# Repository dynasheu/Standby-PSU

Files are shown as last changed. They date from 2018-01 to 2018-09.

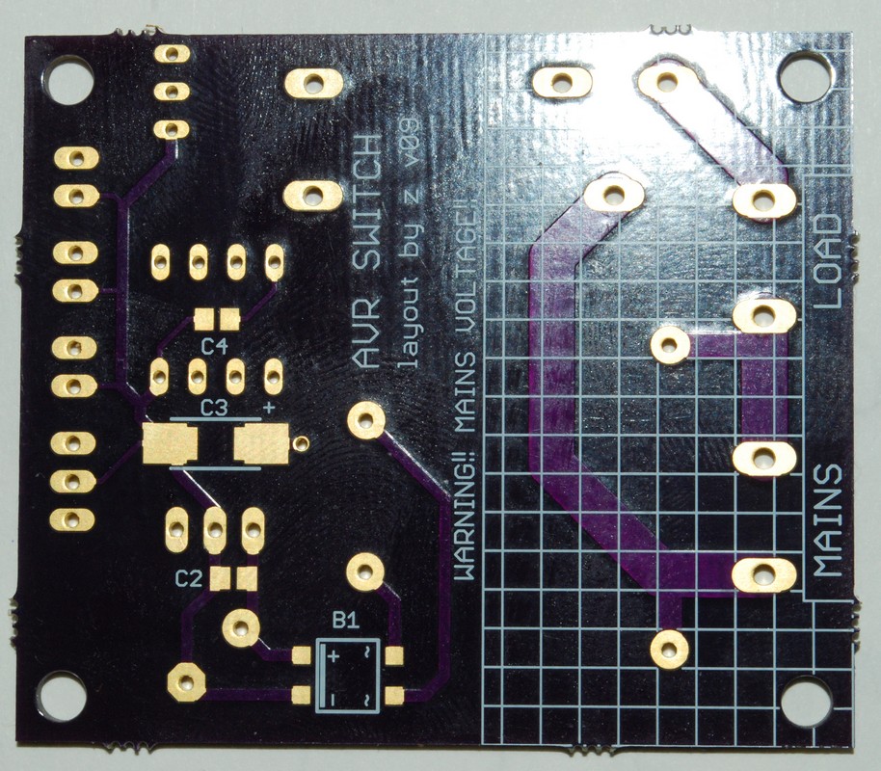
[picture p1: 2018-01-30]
prototype/avr3_v09_cr.jpg

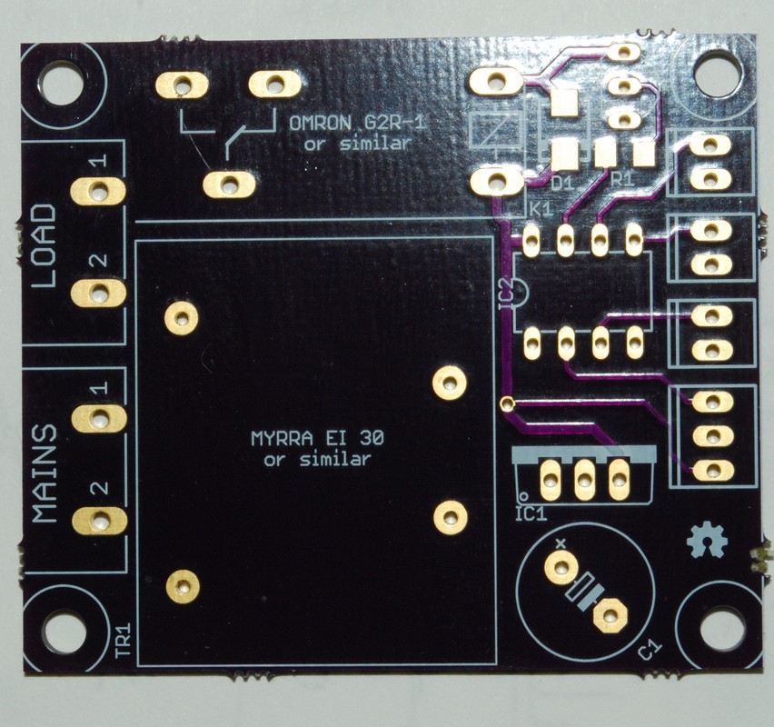
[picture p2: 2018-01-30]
prototype/avr2_v09_cr.jpg

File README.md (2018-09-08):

# Standby-PSU
Small sandby PSU for low power applications.

## standby-psu-test
This sketch is for debugging and testing on arduino. Uses normal IRremote.h library.

## standby-psu-master
This sketch is for use with ATTiny.
Uses tiny_IRremote.h and SendOnlySoftwareSerial.h libraries.

I/O:
- button
- led
- relay
- ir
- serial out

PCB and components coming soon

## standby-psu-slave
Comming soon.

This sketch is for use with ATTiny.
Uses ReceiveOnlySoftwareSerial.h library.

I/O:
- button
- led
- relay
- mute relay
- serial in

Same PCB as master.

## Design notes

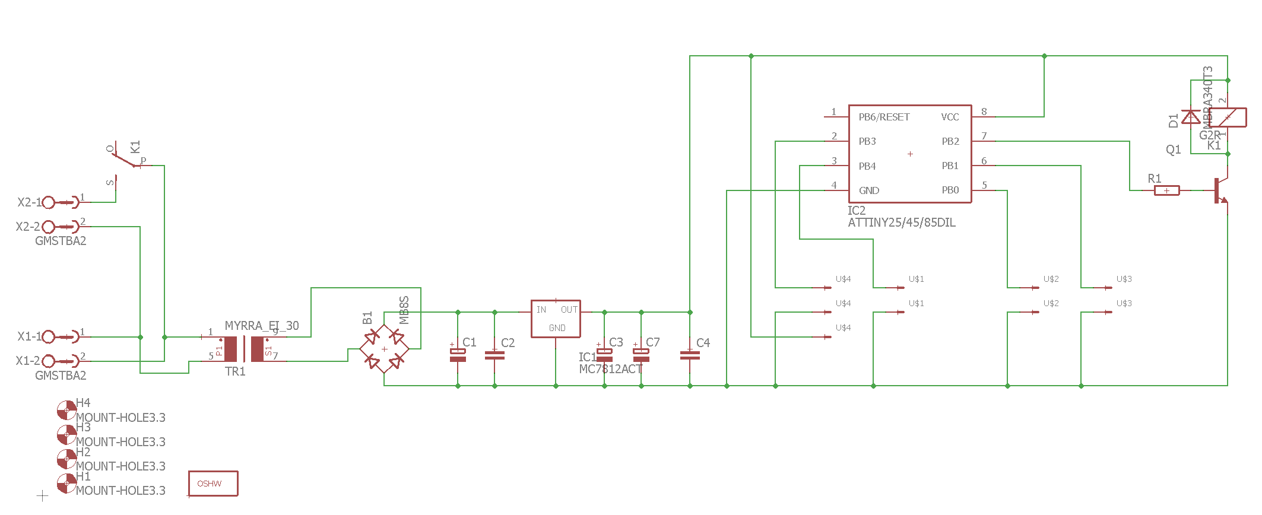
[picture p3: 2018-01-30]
prototype/schematic_avr_v09.PNG

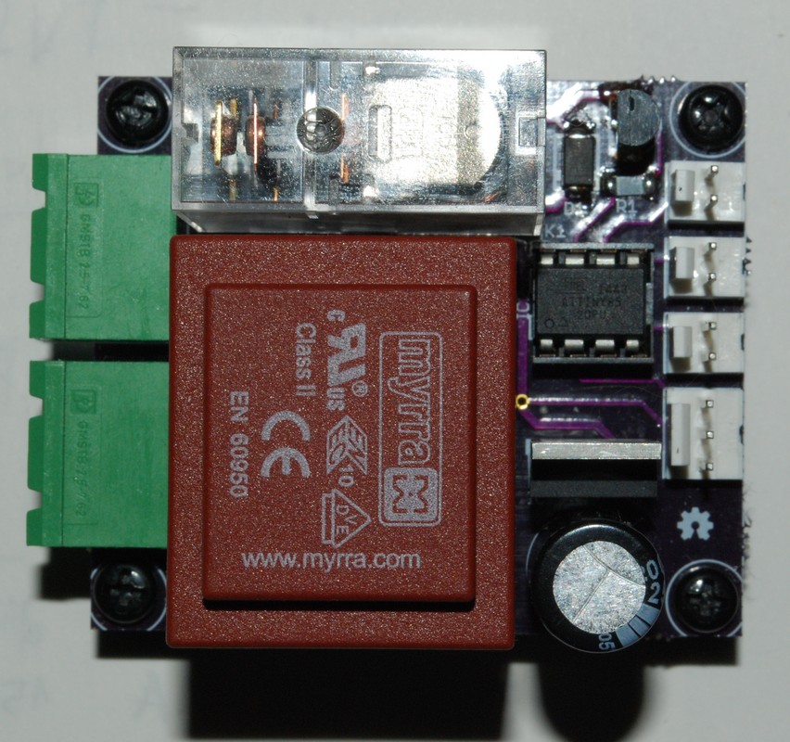
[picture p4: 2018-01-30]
prototype/avr1_v09_cr.jpg

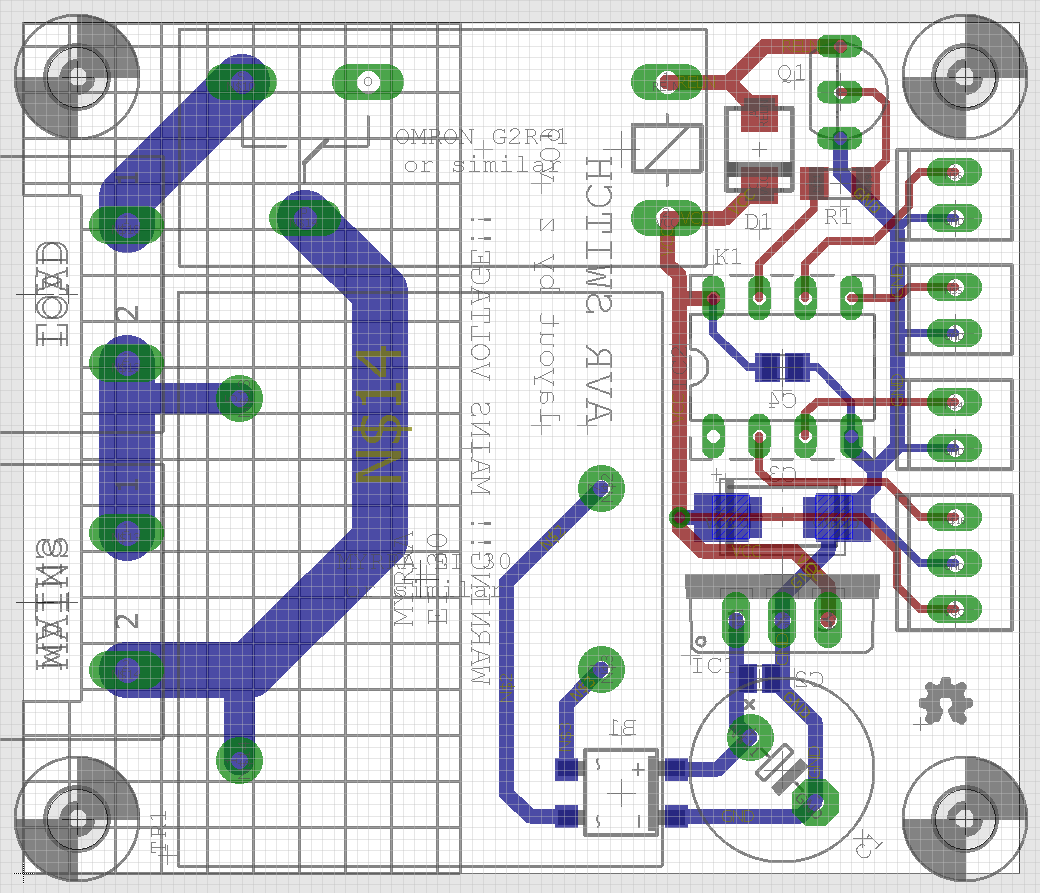
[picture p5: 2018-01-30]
prototype/pcb_avr_v09.PNG

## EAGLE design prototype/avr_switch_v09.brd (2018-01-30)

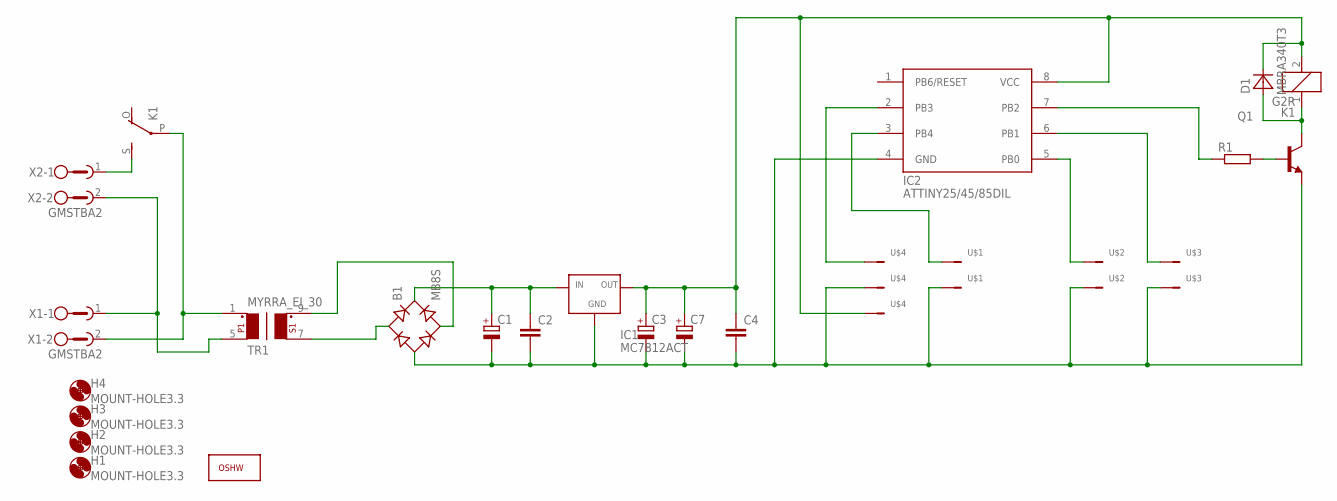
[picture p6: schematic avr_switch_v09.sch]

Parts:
B1: MB8S; SOIC-4
C1: CPOL-EUE5-10.5; E5-10,5
C2, C4: C-EUC0805; C0805
C3: CPOL-EUCT6032; CT6032
C7: CPOL-EUD/7343-31W; D/7343-31W
D1: MBRA340T3; SMA
H1, H2, H3, H4: MOUNT-HOLE3.3; 3,3
IC1: MC7812ACT; TO220V
IC2: ATTINY25/45/85DIL; DIL08
K1: G2R
Q1: BC548-NPN-TO92-CBE; TO92-CBE
R1: R-EU_R1206; R1206
TR1: MYRRA_EI_30; MYRRA-EI30
U$1, U$2, U$3: MOLEX-VERT-KK-2-; MOLEX-KK-VERT-2PIN
U$4: MOLEX-VERT-KK-3-3PIN; MOLEX-KK-VERT-3PIN
U$5: OSHWOSHW_TOP; OSHW_F
X1, X2: GMSTBA2

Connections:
GND: B1.-, C1.-, C2.2, C3.-, C4.2, C7.-, IC1.2 (GND), IC2.4 (GND), Q1.E, U$1.1, U$2.1, U$3.1, U$4.2
unnamed: IC2.7 (PB2), R1.1
unnamed: B1.~1 (AC1), TR1.7
unnamed: B1.~2 (AC2), TR1.9
unnamed: IC2.3 (PB4), U$1.2
unnamed: IC2.5 (PB0), U$2.2
unnamed: IC2.6 (PB1), U$3.2
unnamed: Q1.B, R1.2
unnamed: K1.S, X2.1
unnamed: B1.+, C1.+, C2.1, IC1.1 (IN)
unnamed: TR1.5, X1.1, X2.2
unnamed: K1.P, TR1.1, X1.2
unnamed: IC2.2 (PB3), U$4.3
RELN: D1.A, K1.1, Q1.C
VCC: C3.+, C4.1, C7.+, D1.C, IC1.3 (OUT), IC2.8 (VCC), K1.2, U$4.1

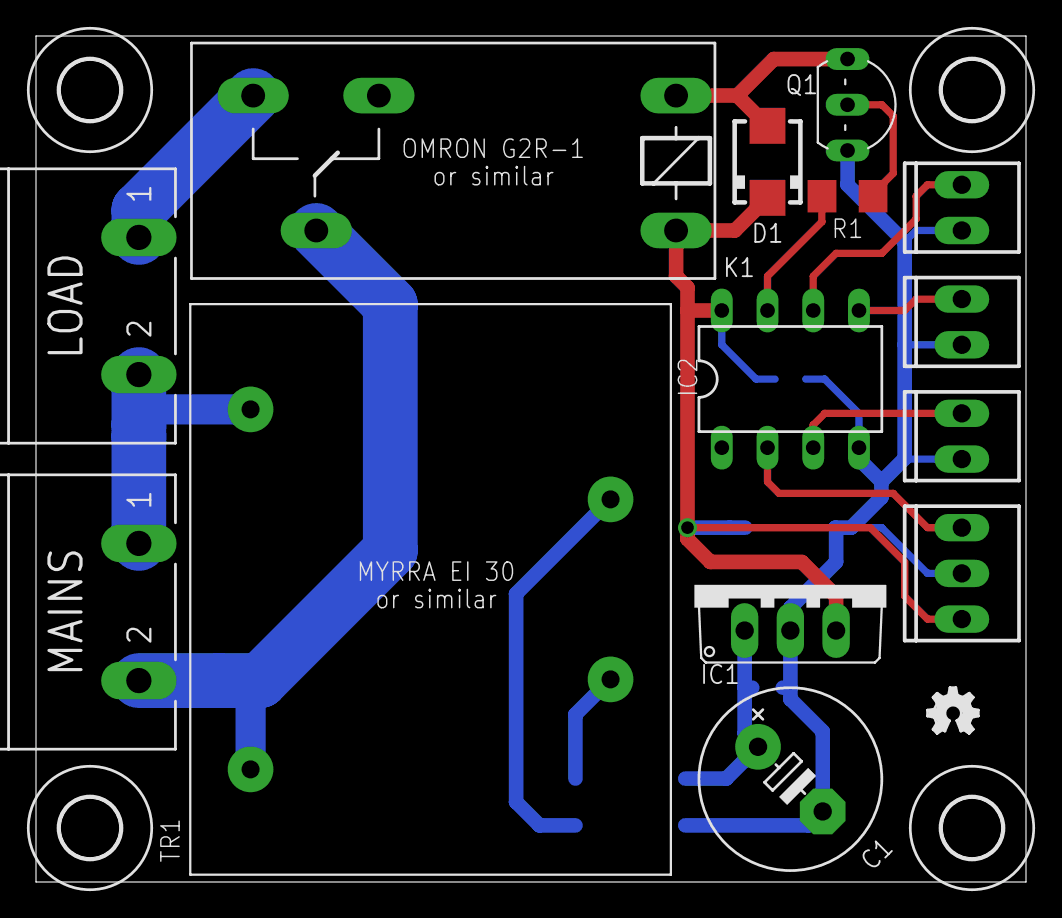
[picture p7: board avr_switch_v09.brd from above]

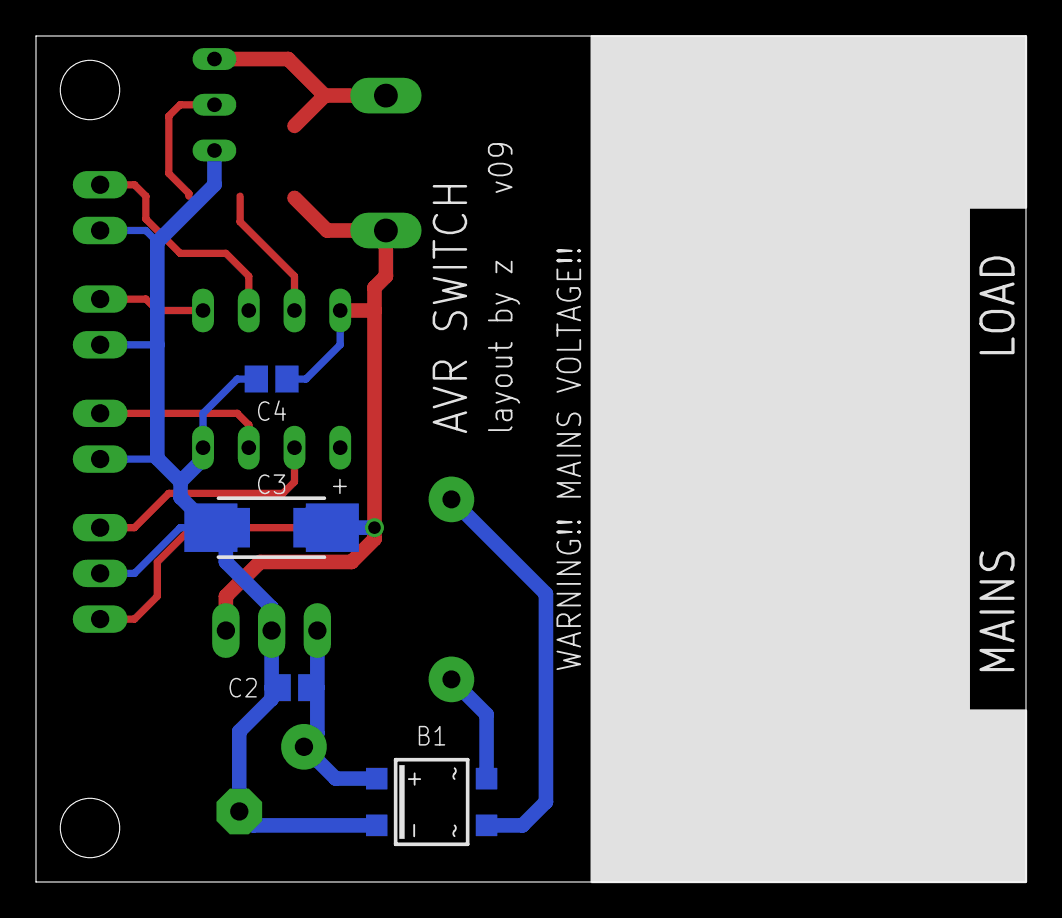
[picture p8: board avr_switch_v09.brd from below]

Board: 2 copper layers, 55.0 x 47.0 mm, 24 parts (5 on the bottom side), 15 nets.

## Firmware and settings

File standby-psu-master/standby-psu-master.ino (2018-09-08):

// load libraries
#include "tiny_IRremote.h"
#include "SendOnlySoftwareSerial.h"

// pinout
#define relayPin PB2                            // ATtiny pin 7
#define ledPin PB1                              // ATtiny pin 6
#define buttonPin PB0                           // ATtiny pin 5
#define serialOutPin PB4                        // ATtiny pin 3
#define irPin PB3                               // ATtiny pin 2

bool ledState = HIGH;                           // state of standby led. turned HIGH when system is off
bool powerState = LOW;                          // power state, LOW when system is off
bool enablePower = HIGH;                        // enable power state change
bool powerSent = LOW;                           // flag to send power down serial out

int debounceDelay = 50;                         // debounce time
unsigned long powerStateTimer = 0;              // time snapshot when power state changed
unsigned long blinkTimer = 0;                   // blink timer
int powerStateDelay = 15000;                    // power state delay time
bool pauseLoop = LOW;                           // pause main loop

// IR setup
IRrecv irrecv(irPin);
decode_results results;

unsigned long muteTimer = 0;                    // millis snapshot when we press mute button on ir (repeating signal)
bool irMute = LOW;                              // check if we can change mute state again with ir
bool irPower = LOW;                             // signal to change power state from ir

// Software serial
SendOnlySoftwareSerial mySerial (serialOutPin);       // Tx pin

void setup() {
    // serial setup
    mySerial.begin (9600);

    // pinout setup
    pinMode(buttonPin, INPUT_PULLUP);
    pinMode(ledPin, OUTPUT);
    pinMode(irPin, INPUT);
    pinMode(relayPin, OUTPUT);
    pinMode(serialOutPin, OUTPUT);

    // defaults
    digitalWrite(ledPin, ledState);
    digitalWrite(relayPin, powerState);

    // ir setup
    irrecv.enableIRIn();
}

void loop() {
    // startup and shutdown blinking led
    if (millis() - powerStateTimer < powerStateDelay) {
        // disable power button
        enablePower = LOW;

        // blink led every second
        if(millis() - blinkTimer > 1000) {
            digitalWrite(ledPin, HIGH);
            delay(debounceDelay);
            digitalWrite(ledPin, LOW);
            blinkTimer = millis();
        }
    }
    else {
        // enable power button
        enablePower = HIGH;

        // reset led state
        digitalWrite(ledPin, ledState);
    }

    // microsoft xbox one media remote - NEC standard
    // 18556633 - logo
    // 18577033 - window
    // 18609673 - lines
    // 18577543 - up
    // 18610183 - down
    // 18547963 - left
    // 18580603 - right
    // 18564283 - center
    // 18596923 - back
    // 18572443 - line dot
    // 18589783 - rewind
    // 18550513 - play
    // 18557143 - forward
    // 18602023 - previous
    // 18585703 - stop
    // 18569383 - next

    // repeating codes
    // 18548983 - volume up
    // 18581623 - volume down
    // 18575503 - mute
    // 18565303 - channel up
    // 18597943 - channel down

    // 4294967295 - resend data

    // read ir
    if (irrecv.decode(&results)) {
        if (results.value == 18556633) { // logo button as power on or off
//            mySerial.println("     ");
            irPower = HIGH;
        }
        if (results.value == 18575503 && irMute == LOW) { // mute button
            mySerial.println("0202");
            irMute = HIGH;
            muteTimer = millis();
        }
        if (results.value == 18548983) { // volume up
            mySerial.println("0301");
        }
        if (results.value == 18581623) { // volume down
            mySerial.println("0302");
        }
        if (results.value == 18609673) { // lines button as change output
            mySerial.println("0401");
        }
        if (results.value == 18577033) { // squares button as change input
            mySerial.println("0501");
        }
        irrecv.resume(); // Receive the next value
    }

    // read button
    int buttonPress = 0;
    while (digitalRead(buttonPin) == LOW && buttonPress < 30) {
        buttonPress++;
        delay(debounceDelay);
    }

    if ( (buttonPress > 29 || irPower == HIGH) && enablePower == HIGH) {
        // power on or off
        if (powerState == HIGH) {
            // turning off

            // send mute over serial
            mySerial.println("0201");

            // wait 3seconds after mute signal before system turns off
            powerSent = LOW;
            int turnOff = 0;
            do {
                digitalWrite(ledPin, !ledState);
                delay(debounceDelay);
                digitalWrite(ledPin, ledState);
                delay(debounceDelay);

                // send power off over serial
                if (turnOff > 10 && powerSent == LOW) {
                    powerSent = HIGH;
                    mySerial.println("0103");
                }

                turnOff++;
            } while (turnOff < 30);

            ledState = powerState;
            powerState = !powerState;
            powerStateTimer = millis();

            // write to digital pins
            digitalWrite(ledPin, ledState);
            digitalWrite(relayPin, powerState);
        }
        else if (powerState == LOW) {
            // turning on
            delay(debounceDelay);

            ledState = powerState;
            powerState = !powerState;
            powerStateTimer = millis();

            // write to digital pins
            digitalWrite(ledPin, ledState);
            digitalWrite(relayPin, powerState);
        }
    }
    else if (buttonPress > 1 && buttonPress < 20 && powerState == HIGH) {
        // send short press signal over serial
        mySerial.println("0900");
    }

    // reset mute operation after 15s
    if (millis() - muteTimer > powerStateDelay && irMute == HIGH) {
        irMute = LOW;
    }

    // pause main loop
    do {
        pauseLoop = LOW;
        if (irrecv.decode(&results)) {
            if (results.value == 4294967295) {   // ir resend data value
                if (irPower == HIGH) {
                    pauseLoop = HIGH;
                }
            }
            irrecv.resume(); // Receive the next value
        }
        if (digitalRead(buttonPin) == LOW ) {
            pauseLoop = HIGH;
        }
        delay(debounceDelay);
    } while (pauseLoop);     // wait for button release

    // reset irPower flag
    irPower = LOW;
}

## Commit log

2018-01-30 Test prototypes of Standby PSU
    Not for actual use.
    [avr_switch_v09.brd, avr_switch_v09.sch]
2018-09-08 added test sketch for testing on arduino
2018-09-08 button and relay portion working
2018-09-08 fixed issue with short press on turn on
    [standby-psu-test.ino]
2018-09-08 pin descriptions
